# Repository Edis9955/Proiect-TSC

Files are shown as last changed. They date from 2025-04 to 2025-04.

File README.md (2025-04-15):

# Diagrama Bloc

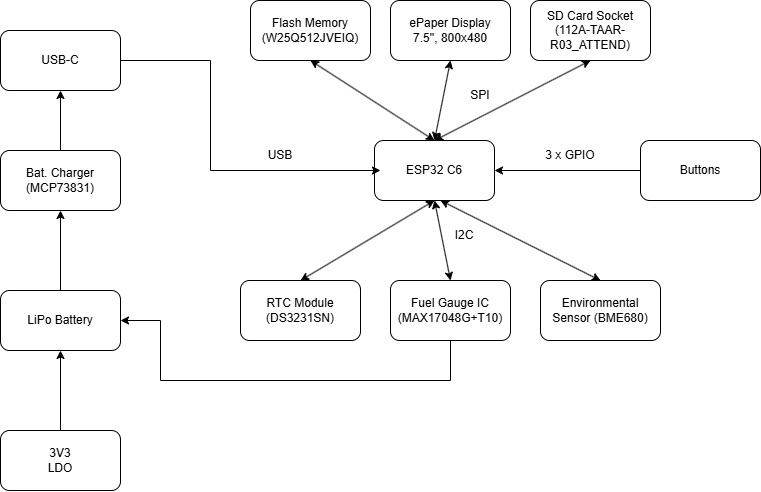
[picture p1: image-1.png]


# Bill of Materials

| Componenta | Descriere | Cumpara | Datasheet |
|---|---|---|---|
| ESP32-C6-WROOM-1-N8 | Microcontroler cu Wi-Fi 6, BLE 5.0 | [Mouser](https://ro.mouser.com/ProductDetail/Espressif-Systems/ESP32-C6-WROOM-1-N8) | [Datasheet](https://www.espressif.com/sites/default/files/documentation/esp32-c6-wroom-1_wroom-1u_datasheet_en.pdf) |
| BME680 | Senzor temperatură, umiditate, presiune, VOC | [Mouser](https://ro.mouser.com/ProductDetail/Bosch-Sensortec/BME680) | [Datasheet](https://www.bosch-sensortec.com/media/boschsensortec/downloads/datasheets/bst-bme680-ds001.pdf) |
| DS3231SN | Ceas în timp real | [Mouser](https://ro.mouser.com/ProductDetail/Analog-Devices/DS3231SN) | [Datasheet](https://www.analog.com/media/en/technical-documentation/data-sheets/DS3231.pdf) |
| W25Q512JVEIQ | Memorie Flash 64MB | [Mouser](https://ro.mouser.com/ProductDetail/Winbond/W25Q512JVEIQ) | [Datasheet](https://www.winbond.com/resource-files/W25Q512JV%20SPI%20RevB%2006252019%20KMS.pdf) |
| MicroSD Slot (112A-TAAR-R03) | Slot card microSD | [Mouser](https://ro.mouser.com/ProductDetail/Attend/112A-TAAR-R03) | [Datasheet](https://www.attend.com.tw/data/download/file/112A-TAAR-R03_Spec.pdf) |
| MCP73831T-5ACI/OT | Încărcător baterie | [Mouser](https://ro.mouser.com/ProductDetail/Microchip-Technology/MCP73831T-5ACI-OT) | [Datasheet](https://ww1.microchip.com/downloads/en/DeviceDoc/MCP73831-Family-Data-Sheet-DS20001984H.pdf) |
| MAX17048G+T10 | Indicator nivel baterie | [Mouser](https://ro.mouser.com/ProductDetail/Analog-Devices/MAX17048G%2BT10) | [Datasheet](https://www.analog.com/media/en/technical-documentation/data-sheets/MAX17048-MAX17049.pdf) |
| XC6220A331MR-G | Regulator 3.3V | [Mouser](https://ro.mouser.com/ProductDetail/Torex-Semiconductor/XC6220A331MR-G) | [Datasheet](https://www.torexsemi.com/file/xc6220/XC6220.pdf) |
| USB4110-GF-A | Conector USB-C | [Mouser](https://ro.mouser.com/ProductDetail/GCT/USB4110-GF-A) | [Datasheet](https://gct.co/files/drawings/usb4110.pdf) |
| CPH3225A | Supercondensator pentru ceas | [Mouser](https://ro.mouser.com/ProductDetail/Seiko-Instruments/CPH3225A) | [Datasheet](https://mm.digikey.com/Volume0/opasdata/d220001/medias/docus/6537/rev05-CPHCPM.pdf) |
| DMG2305UX-7 | MOSFET P-Channel | [Mouser](https://ro.mouser.com/ProductDetail/Diodes-Incorporated/DMG2305UX-7) | [Datasheet](https://www.diodes.com/assets/Datasheets/DMG2305UX.pdf) |
| SI1308EDL-T1-GE3 | MOSFET N-Channel | [Mouser](https://ro.mouser.com/ProductDetail/Vishay-Siliconix/SI1308EDL-T1-GE3) | [Datasheet](https://www.vishay.com/docs/63399/si1308edl.pdf) |
| USBLC6-2SC6Y | Protecție ESD USB | [Mouser](https://ro.mouser.com/ProductDetail/STMicroelectronics/USBLC6-2SC6Y) | [Datasheet](https://www.st.com/resource/en/datasheet/usblc6-2.pdf) |
| PGB1010603MR | Protecție ESD | [Mouser](https://ro.mouser.com/ProductDetail/Littelfuse/PGB1010603MR) | [Datasheet](https://www.littelfuse.com/~/media/electronics/datasheets/esd_protection/littelfuse_pulseguard_esd_pgb1_series_datasheet.pdf) |
| BD5229G-TR | Detector tensiune | [Mouser](https://ro.mouser.com/ProductDetail/ROHM-Semiconductor/BD5229G-TR) | [Datasheet](https://fscdn.rohm.com/en/products/databook/datasheet/ic/power/voltage_detector/bd52xxg-e.pdf) |
| FH34SRJ-24S-0.5SH(99) | Conector FFC/FPC e-paper | [Mouser](https://ro.mouser.com/ProductDetail/Hirose-Connector/FH34SRJ-24S-0.5SH99) | [Datasheet](https://www.hirose.com/product/document?clcode=&productname=&series=FH34SRJ&documenttype=Catalog&lang=en) |
| 744043680 | Inductor | [Mouser](https://ro.mouser.com/ProductDetail/Wurth-Elektronik/744043680) | [Datasheet](https://www.we-online.com/components/products/datasheet/744043680.pdf) |
| EVQPUJ02K | Buton tactil | [Mouser](https://ro.mouser.com/ProductDetail/Panasonic/EVQPUJ02K) | [Datasheet](https://www.lcsc.com/datasheet/lcsc_datasheet_2201121800_PANASONIC-EVQPUJ02K_C2936858.pdf) |
| KP-1608SURCK | LED indicator | [Mouser](https://ro.mouser.com/ProductDetail/Kingbright/KP-1608SURCK) | [Datasheet](https://media.elv.com/file/107153_led_surck1608_data.pdf) |

# Functionalitati Hardware
### ESP32-C6-WROOM-1-N8
- MCU principal, Wi-Fi 6, Bluetooth 5
- Interfețe: SPI, I2C, UART, GPIO
- 160MHz, 512KB SRAM, 8MB Flash

### Senzor BME688
- Măsoară: temperatură, umiditate, presiune, VOC
- I2C, consum redus: <1mA

### Ecran E-Paper
- Diagonală: 7.5”
- Conectare prin SPI
- Consum 0 în stare statică

### Sistem de Alimentare
- Baterie: 3.7V Li-Po 2500mAh
- Încărcare: MCP73831, max 1A
- Monitorizare: MAX17048 (Fuel Gauge)
- Consum tipic:
- Activ: ~150mA
- Standby: ~10mA
- Deep Sleep: <50µA
- Autonomie: ~250h la 10mA

### Conectivitate USB-C
- Încărcare & date (USB 2.0)
- Protecție ESD: USBLC6-2SC6Y

# Descriere pini

| Pin  | Funcție | Componentă | Descriere Utilizare |
|-----:|:---|:---|:---|
| EN  | RESET | Resetare sistem |Pin pentru resetare
| GPIO0  | BOOT_BUTTON | Buton | Boot mode la pornire |
| GPIO1  | RESET_BUTTON | Buton | Reset manual |
| GPIO2  | CHANGE_BUTTON  | Buton | Navigare meniu |
| GPIO3  | EPD_CS | Display E-Paper | Chip Select (SPI) |
| GPIO4  | EPD_DC | Display E-Paper | Data/Command control |
| GPIO5  | EPD_RST | Display E-Paper | Reset ecran |
| GPIO6  | EPD_BUSY | Display E-Paper | Semnal stare refresh |
| GPIO7  | SPI_MOSI | Display, Flash, SD  | Master Out Slave In (SPI) |
| GPIO8  | SPI_MISO | Display, Flash, SD  | Master In Slave Out (SPI) |
| GPIO9  | SPI_SCK | Display, Flash, SD  | Clock SPI |
| GPIO10 | FLASH_CS | W25Q512JVEIQ | Chip Select pentru Flash |
| GPIO11 | SD_CS | Micro SD (opțional) | Chip Select card SD |
| GPIO12 | I2C_SDA | BME680, MAX17048, DS3231 | Linie date I2C |
| GPIO13 | I2C_SCL | BME680, MAX17048, DS3231 | Linie clock I2C | 
| GPIO14 | CHG_LED | LED încărcare | Status încărcare |
| GPIO15 | UART_TX | Debugging | TX serial |
| GPIO16 | UART_RX | Debugging | RX serial |
| GPIO17 | USB_D+ | USB-C | Linie date USB + |
| GPIO18 | USB_D- | USB-C | Linie date USB – 
| GPIO21 | SDA | Linie date I²C | Comun pentru senzori si RTC |
| GPIO22 | SCL | Linie ceas I²C | Semnal comun de ceas I²C |
| GPIO23 | EPD_RST | Resetare e-paper | Resetare hardware pentru afișaj |
| TXD0 | TX | Transmitere UART (depanare) | Punct test pentru depanare |
| RXD0 | RX | Recepție UART (depanare) | Punct test pentru depanare | |

## observatii:
- fisierul Mechanical si Images nu au fost inca populate
- componentele SPI ESD Protection Lines sunt foarte grupate
- toate test pad-urile sunt pe pcb, desi in model doar 5 erau

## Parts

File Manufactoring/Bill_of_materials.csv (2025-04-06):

Qty | Value | Device | Package | Parts | Description | ARROW_PART_NUMBER | ARROW_PRICE-STOCK | AVAILABILITY | CENTROID_NOT_SPECIFIED | CHECK_PRICES | COPYRIGHT | DATASHEET | DESCRIPTION | DIGIKEY_DESCRIPTION | DIGIKEY_PART_NUMBER | FOOTPRINT | HEIGHT | LEAD_FREE | MANUFACTURER_NAME | MANUFACTURER_PART_NUMBER | MF | MFR_NAME | MOUSER_PART_NUMBER | MOUSER_PRICE-STOCK | MOUSER_TESTING_PART_NUMBER | MOUSER_TESTING_PRICE-STOCK | MP | MPN | PACKAGE | POPULARITY | PREFIX | PRICE | PROD_ID | PURCHASE-URL | ROHS | SNAPEDA_LINK | SPICEMODEL | SPICEPREFIX | TEMPERATURE_RANGE_HIGH | TEMPERATURE_RANGE_LOW | TP_SIGNAL_NAME | VALUE
1 |  | ADAFRUIT_LEDCHIP-LED0603 | ADAFRUIT_CHIP-LED0603 | CHG_LED | LED
1 |  | ESP32C6_VARISTORCN1812 | ESP32C6_VARISTOR_CT/CN1812 | PFMF.050.1 | VARISTOR |  |  |  |  |  |  |  |  |  |  |  |  |  |  |  |  |  |  |  |  |  |  |  |  | 0
1 |  | ESP32_WROVER_SPARKFUN-IC-POWER_MCP73831 | ESP32_WROVER_SPARKFUN-IC-POWER_SOT23-5 | MCP73831 | MCP73831T Li-Ion, Li-Pol Controller |  |  |  |  |  |  |  |  |  |  |  |  |  |  |  |  |  |  |  |  |  |  |  |  |  |  |  | IC-09995
1 |  | SJ | SJ | SJ1 | SMD solder JUMPER |  |  |  |  |  |  |  |  |  |  |  |  |  |  |  |  |  |  |  |  |  |  |  |  | 3
1 | 0.47 | ESP32_WROVER_EAGLE-LTSPICE_RR0402 | ESP32_WROVER_EAGLE-LTSPICE_R0402 | R3 | RESISTOR, European symbol |  |  |  |  |  |  |  |  |  |  |  |  |  |  |  |  |  |  |  |  |  |  |  |  |  |  |  |  |  |  |  | NONE | R
2 | 100K | ESP32_WROVER_EAGLE-LTSPICE_RR0402 | ESP32_WROVER_EAGLE-LTSPICE_R0402 | R1-PWRUSB, R1-PWRUSB1 | RESISTOR, European symbol |  |  |  |  |  |  |  |  |  |  |  |  |  |  |  |  |  |  |  |  |  |  |  |  |  |  |  |  |  |  |  | NONE | R
8 | 100nF | EAGLE-LTSPICE_CC0402 | EAGLE-LTSPICE_C0402 | C1, C2, C5, C6, C8, C9, C10, C_DELAY | CAPACITOR, European symbol |  |  |  |  |  |  |  |  |  |  |  |  |  |  |  |  |  |  |  |  |  |  |  |  |  |  |  |  |  |  |  | NONE | C
2 | 100nf | EAGLE-LTSPICE_CC0402 | EAGLE-LTSPICE_C0402 | C4, C4_USB | CAPACITOR, European symbol |  |  |  |  |  |  |  |  |  |  |  |  |  |  |  |  |  |  |  |  |  |  |  |  |  |  |  |  |  |  |  | NONE | C
1 | 100uF TANT | RCL_CPOL-EUCT3528 | RCL_CT3528 | C3 | POLARIZED CAPACITOR, European symbol |  |  |  |  |  |  |  |  |  |  |  |  |  |  |  |  |  |  |  |  |  |  |  |  | 0 |  |  |  |  |  |  |  | C
16 | 10K | ESP32_WROVER_EAGLE-LTSPICE_RR0402 | ESP32_WROVER_EAGLE-LTSPICE_R0402 | R1_PINH, R1_PINH1, R2_PINH, R2_PINH1, R4, R5, R6, R7, R8, R9, R10, R_BOOT, R_CAPACITOR, R_CHANGE, R_CL1, R_RESET | RESISTOR, European symbol |  |  |  |  |  |  |  |  |  |  |  |  |  |  |  |  |  |  |  |  |  |  |  |  |  |  |  |  |  |  |  | NONE | R
1 | 10uF | EAGLE-LTSPICE_CC0402 | EAGLE-LTSPICE_C0402 | C7 | CAPACITOR, European symbol |  |  |  |  |  |  |  |  |  |  |  |  |  |  |  |  |  |  |  |  |  |  |  |  |  |  |  |  |  |  |  | NONE | C
1 | 112A-TAAR-R03_ATTEND | 112A-TAAR-R03_ATTEND | 112ATAARR03ATTEND | J4 | Micro SD Card Socket, Push-Push Type, Top Mount, SMT, H=1.83mm, 10u |  |  |  |  |  |  |  | Micro SD Card Socket | Push-Push Type | Top Mount | SMT | H=1.83mm | 10u |  |  |  | 1.9mm |  | ATTEND | 112A-TAAR-R03 ATTEND
10 | 1uF/50V | EAGLE-LTSPICE_CC0402 | EAGLE-LTSPICE_C0402 | EPD_C1, EPD_C2, EPD_C5, EPD_C6, EPD_C7, EPD_C8, EPD_C9, EPD_C10, EPD_C11, EPD_C12 | CAPACITOR, European symbol |  |  |  |  |  |  |  |  |  |  |  |  |  |  |  |  |  |  |  |  |  |  |  |  |  |  |  |  |  |  |  | NONE | C
1 | 2.2 | ESP32_WROVER_EAGLE-LTSPICE_RR0402 | ESP32_WROVER_EAGLE-LTSPICE_R0402 | R2 | RESISTOR, European symbol |  |  |  |  |  |  |  |  |  |  |  |  |  |  |  |  |  |  |  |  |  |  |  |  |  |  |  |  |  |  |  | NONE | R
1 | 200 | ESP32_WROVER_EAGLE-LTSPICE_RR0402 | ESP32_WROVER_EAGLE-LTSPICE_R0402 | R1_BAT | RESISTOR, European symbol |  |  |  |  |  |  |  |  |  |  |  |  |  |  |  |  |  |  |  |  |  |  |  |  |  |  |  |  |  |  |  | NONE | R
2 | 20V/4.2A/52mO/1.4W | ESP32_WROVER_SPARKFUN-DISCRETESEMI_MOSFET_PCH-DMG2305UX-7 | ESP32_WROVER_SPARKFUN-DISCRETESEMI_SOT23-3 | Q1, Q2 | P-channel MOSFETs |  |  |  |  |  |  |  |  |  |  | DMG2305UX-7 |  |  |  |  |  |  |  |  |  |  |  |  |  |  |  |  | TRAN-14388 |  |  |  |  |  |  |  |  | 20V/4.2A/52mO/1.4W
1 | 2K | ESP32_WROVER_EAGLE-LTSPICE_RR0402 | ESP32_WROVER_EAGLE-LTSPICE_R0402 | R2_BAT | RESISTOR, European symbol |  |  |  |  |  |  |  |  |  |  |  |  |  |  |  |  |  |  |  |  |  |  |  |  |  |  |  |  |  |  |  | NONE | R
2 | 4.7uF | EAGLE-LTSPICE_CC0402 | EAGLE-LTSPICE_C0402 | C1_BAT, C2_BAT | CAPACITOR, European symbol |  |  |  |  |  |  |  |  |  |  |  |  |  |  |  |  |  |  |  |  |  |  |  |  |  |  |  |  |  |  |  | NONE | C
3 | 4.7uf | EAGLE-LTSPICE_CC0402 | EAGLE-LTSPICE_C0402 | C1_BAT1, C1_BAT2, C5_USB | CAPACITOR, European symbol |  |  |  |  |  |  |  |  |  |  |  |  |  |  |  |  |  |  |  |  |  |  |  |  |  |  |  |  |  |  |  | NONE | C
2 | 5K1 | ESP32_WROVER_EAGLE-LTSPICE_RR0402 | ESP32_WROVER_EAGLE-LTSPICE_R0402 | R2-USB1, R2-USB2 | RESISTOR, European symbol |  |  |  |  |  |  |  |  |  |  |  |  |  |  |  |  |  |  |  |  |  |  |  |  |  |  |  |  |  |  |  | NONE | R
1 | 68uH | 744043680IND_4828-WE-TPC_WRE | IND_4828-WE-TPC_WRE | L1 |  |  |  |  |  |  | Copyright (C) 2024 Ultra Librarian. All rights reserved. |  |  |  |  |  |  |  |  | 744043680 |  | Wurth Electronics
1 | BD5229G-TR | BD5229G-TR | SOT95P280X125-5N | IC11 | Voltage Detector with Adjustable Delay Time: CMOS processes are utilized to develop high precision, low current consumption CMOS reset ICs that allow arbitrary setting of the delay time. The extensive lineup includes both Nch Open Drain and CMOS output types in a wide range of detection voltages (from 2.3V to 6.0V, in 0.1V steps), enabling selection of the ideal solution based on customer requirements. In addition, the entire series is of course both lead-free and RoHS-compliant. |  |  |  |  |  |  |  | Voltage Detector with Adjustable Delay Time: CMOS processes are utilized to develop high precision | low current consumption CMOS reset ICs that allow arbitrary setting of the delay time. The extensive lineup includes both Nch Open Drain and CMOS output types in a wide range of detection voltages (from 2.3V to 6.0V | in 0.1V steps) | enabling selection of the ideal solution based on customer requirements. In addition | the entire series is of course both lead-free and RoHS-compliant. |  |  |  | 1.25mm |  | ROHM Semiconductor | BD5229G-TR |  |  | 755-BD5229G-TR | https://www.mouser.co.uk/ProductDetail/ROHM-Semiconductor/BD5229G-TR?qs=4kLU8WoGk0vvnhrrYwdszw%3D%3D
1 | BME688 | ESP32_WROVER_BME680_BME680 | ESP32_WROVER_BME680_PSON80P300X300X100-8N | SENSOR2 | Integrated Environmental Unit |  |  | Unavailable |  |  |  |  | Integrated Environmental Unit |  |  |  |  |  |  |  | Bosch Sensortec |  |  |  |  |  | BME680 |  | LGA-8 Bosch Tools |  |  | None
3 | BUTTON_CUSYOMV1 | BUTTON_CUSYOMV1 | MYBUTTON | BOOT_BUTTON, CHANGE_BUTTON, RESET_BUTTON
1 | CPH3225A | CPH3225A | CAPCP3225X100N | C10_SUPERCAP | Cap 0.011F 3.3V 1210 Flat Check availability |  |  | Not in stock |  | https://www.snapeda.com/parts/CPH3225A/Seiko+Instruments/view-part/?ref=eda |  |  | 11 mF (EDLC) Supercapacitor 3.3 V 1210 (3225 Metric) - - |  |  |  |  |  |  |  | Seiko Instruments |  |  |  |  |  | CPH3225A |  | 1210 Seiko |  |  | None |  | https://www.snapeda.com/api/url_track_click_mouser/?unipart_id=562593&manufacturer=Seiko Instruments&part_name=CPH3225A&search_term=None |  | https://www.snapeda.com/parts/CPH3225A/Seiko+Instruments/view-part/?ref=snap
1 | DS3231SN# | DS3231SN# | SOIC127P1032X265-16N | U11 | Real Time Clock Serial 16-Pin SOIC W T/R Check availability |  |  | In Stock |  | https://www.snapeda.com/parts/DS3231SN%23/Analog+Devices/view-part/?ref=eda |  |  | Extremely Accurate I²C-Integrated RTC/TCXO/Crystal |  |  |  |  |  |  |  | Analog Devices |  |  |  |  |  | DS3231SN# |  | SOIC-16 Maxim |  |  | None |  | https://www.snapeda.com/api/url_track_click_mouser/?unipart_id=99048&manufacturer=Analog Devices&part_name=DS3231SN#&search_term=None |  | https://www.snapeda.com/parts/DS3231SN%23/Analog+Devices/view-part/?ref=snap
1 | ESP32-C6-WROOM-1-N8 | ESP32-C6-WROOM-1-N8 | XCVR_ESP32-C6-WROOM-1-N8 | U21 | Check availability |  |  | In Stock |  | https://www.snapeda.com/parts/ESP32-C6-WROOM-1-N8/Espressif+Systems/view-part/?ref=eda |  |  | Multiprotocol Modules ESP32-C6 module | Wi-Fi 6 in 2.4 GHz band | Bluetooth 5 | Zigbee 3.0 and Thread. ESP34-WROOM Compatible - ENGINEERING SAMPLE |  |  |  |  |  |  |  | Espressif Systems |  |  |  |  |  | ESP32-C6-WROOM-1-N8 |  | None |  |  | None |  |  |  | https://www.snapeda.com/parts/ESP32-C6-WROOM-1-N8/Espressif+Systems/view-part/?ref=snap
2 | ESP32_WROVER_AVX---SD0805S020S1R0_AVX_SD0805S020S1R0_0_0AVX_SD0805S020S1R0_0_0 | ESP32_WROVER_AVX---SD0805S020S1R0_AVX_SD0805S020S1R0_0_0AVX_SD0805S020S1R0_0_0 | ESP32_WROVER_AVX---SD0805S020S1R0_AVX_SD0805S020S1R0_0 | D2, D7 | Schottky Barrier Rectifier Diode |  |  |  | No |  |  | http://datasheets.avx.com/schottky.pdf |  | DIODE SCHOTTKY 20V 1A 0805 | 478-7800-1-ND | SD0805S020S1R0 |  | yes |  |  | AVX |  | 581-SD0805S020S1R0 |  |  |  |  |  | 0805 (2012 metric) |  | D |  |  |  | yes |  |  |  | +125°C | -55°C
1 | FH34SRJ-24S-0.5SH_99_ | FH34SRJ-24S-0.5SH_99_ | FH34SRJ24S05SH99 | J1 | (0.50mm) Surface Mount, Right Angle |  |  |  |  |  |  |  | 24 Position FFC | FPC Connector Contacts | (0.50mm) Surface Mount | Right Angle |  |  |  | 1.1mm |  | Hirose | FH34SRJ-24S-0.5SH(99) |  |  | 798-FH34SRJ24S05SH99 | https://www.mouser.co.uk/ProductDetail/Hirose-Connector/FH34SRJ-24S-0.5SH99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
1 | MAX17048G+T10 | MAX17048G+T10 | SON50P200X200X80-9N | U4 | Check availability |  |  | In Stock |  | https://www.snapeda.com/parts/MAX17048G+T10/Analog+Devices/view-part/?ref=eda |  |  | 3µA 1-Cell/2-Cell Fuel Gauge with ModelGauge |  |  |  |  |  |  |  | Analog Devices |  |  |  |  |  | MAX17048G+T10 |  | TDFN-8 Maxim |  |  | None |  | https://www.snapeda.com/api/url_track_click_mouser/?unipart_id=329239&manufacturer=Analog Devices&part_name=MAX17048G+T10&search_term=None |  | https://www.snapeda.com/parts/MAX17048G+T10/Analog+Devices/view-part/?ref=snap
3 | MBR0530 | MBR0530 | SOD3716X135N | D3, D4, D5 | ON SEMICONDUCTOR - MBR0530 - DIODE, SCHOTTKY, 0.5A, 30V, SOD-123 |  |  | In Stock |  | https://www.snapeda.com/parts/MBR0530/Onsemi/view-part/?ref=eda |  |  | Diode Schottky 30 V 500mA Surface Mount SOD-123 |  |  |  |  |  |  |  | ON Semiconductor |  |  |  |  |  | MBR0530 |  | SOD-123-2 ON Semiconductor |  |  | None |  | https://www.snapeda.com/api/url_track_click_mouser/?unipart_id=179458&manufacturer=ON Semiconductor&part_name=MBR0530&search_term=None |  | https://www.snapeda.com/parts/MBR0530/Onsemi/view-part/?ref=snap
6 | PGB1010603MR | PGB1010603MR | DIOC1608X36N | D6, D8, D9, D10, D12, D13 | Check availability |  |  | In Stock |  | https://www.snapeda.com/parts/PGB1010603MR/Littelfuse/view-part/?ref=eda |  |  | 150V (Typ) Clamp - Ipp Tvs Diode Surface Mount 0603 (1608 Metric) |  |  |  |  |  |  |  | Littelfuse Inc. |  |  |  |  |  | PGB1010603MR |  | 0603 Littelfuse Inc. |  |  | None |  | https://www.snapeda.com/api/url_track_click_mouser/?unipart_id=5659453&manufacturer=Littelfuse Inc.&part_name=PGB1010603MR&search_term=None |  | https://www.snapeda.com/parts/PGB1010603MR/Littelfuse/view-part/?ref=snap
1 | QWIIC_RIGHT_ANGLE | QWIIC_CONNECTORJS-1MM | JST04_1MM_RA | J3 | SparkFun I2C Standard Qwiic Connector |  |  |  |  |  |  |  |  |  |  |  |  |  |  |  |  |  |  |  |  |  |  |  |  |  |  |  | CONN-13694 |  |  |  |  |  |  |  |  | QWIIC_RIGHT_ANGLE
1 | SAMACSYS_PARTS_USB4110-GF-A | SAMACSYS_PARTS_USB4110-GF-A | SAMACSYS_PARTS_USB4110GFA | J2 | CONN USB 2.0 TYPE-C R/A SMT |  |  |  |  |  |  |  | CONN USB 2.0 TYPE-C R/A SMT |  |  |  | 3.26mm |  | GCT (GLOBAL CONNECTOR TECHNOLOGY) | USB4110-GF-A |  |  | 640-USB4110-GF-A | https://www.mouser.co.uk/ProductDetail/GCT/USB4110-GF-A?qs=KUoIvG%2F9IlYiZvIXQjyJeA%3D%3D
1 | SI1308EDL-T1-GE3 | SI1308EDL-T1-GE3 | SOT65P210X110-3N | Q3 | MOSFET N-Ch 30V 1.5A TrenchFET SC70 Vishay Si1308EDL-T1-GE3 N-channel MOSFET Transistor, 1.5 A, 30 V, 3-Pin SC-70 |  |  | In Stock |  | https://www.snapeda.com/parts/SI1308EDL-T1-GE3/Vishay+Siliconix/view-part/?ref=eda |  |  | Si1308EDL-T1-GE3 N-channel MOSFET Transistor | 1.5 A | 30 V | 3-Pin SC-70 | Siliconix / Vishay SI1308EDL-T1-GE3 |  |  |  |  |  |  |  | Vishay Siliconix |  |  |  |  |  | SI1308EDL-T1-GE3 |  | SOT-323 Vishay Semiconductor |  |  | None |  | https://www.snapeda.com/api/url_track_click_mouser/?unipart_id=274603&manufacturer=Vishay Siliconix&part_name=SI1308EDL-T1-GE3&search_term=None |  | https://www.snapeda.com/parts/SI1308EDL-T1-GE3/Vishay+Siliconix/view-part/?ref=snap
17 | TPTP20R | TPTP20R | TP20R | TP1, TP2, TP3, TP4, TP5, TP6, TP7, TP8, TP9, TP10, TP11, TP12, TP13, TP14, TP15, TP16, TP17 | Test pad |  |  |  |  |  |  |  |  |  |  |  |  |  |  |  |  |  |  |  |  |  |  |  |  | 2
1 | USBLC6-2SC6Y | USBLC6-2SC6Y | SOT95P280X145-6N | D1 | Low Cap. ESD Protection Auto SOT-23-6 STMicroelectronics USBLC6-2SC6Y, Dual Uni-Directional TVS Diode Array, 6-Pin SOT-23 |  |  | In Stock |  | https://www.snapeda.com/parts/USBLC6-2SC6Y/STMicroelectronics/view-part/?ref=eda |  |  | 17V Clamp 5A (8/20µs) Ipp Tvs Diode Surface Mount SOT-23-6 |  |  |  |  |  |  |  | STMicroelectronics |  |  |  |  |  | USBLC6-2SC6Y |  | SOT-23-6 STMicroelectronics |  |  | None |  |  |  | https://www.snapeda.com/parts/USBLC6-2SC6Y/STMicroelectronics/view-part/?ref=snap
1 | W25Q512JVEIQ | W25Q512JVEIQ | SON127P600X800X80-9N | U1 | Check availability |  |  | In Stock |  | https://www.snapeda.com/parts/W25Q512JVEIQ/Winbond+Electronics/view-part/?ref=eda |  |  | FLASH - NOR Memory IC 512Mb (64M x 8) SPI - Quad I/O 133 MHz 8-WSON (8x6) |  |  |  |  |  |  |  | Winbond Electronics |  |  |  |  |  | W25Q512JVEIQ |  | Package |  |  | None |  |  |  | https://www.snapeda.com/parts/W25Q512JVEIQ/Winbond+Electronics/view-part/?ref=snap
1 | XC6220A331MR-G | XC6220A331MR-G | SOT95P280X120-5N | IC4 | LDO Voltage Regulators |  |  |  |  |  |  |  | LDO Voltage Regulators |  |  |  | 1.2mm |  | Torex | XC6220A331MR-G |  |  | 865-XC6220A331MR-G | https://www.mouser.co.uk/ProductDetail/Torex-Semiconductor/XC6220A331MR-G?qs=AsjdqWjXhJ8ZSWznL1J0gg%3D%3D

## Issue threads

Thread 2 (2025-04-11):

[invalid] CAD ERC errors

Alexandru730, 2025-04-11:
Ai aprobat 16 erori in schematic, verificarea ERC nu este completa si curata si nu vei putea sa faci randarea in 3D. Singura eroare pe care poti sa o ignori este “Only INPUT pins on NET ID”.

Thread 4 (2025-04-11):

[bug] Wrong placed component

Alexandru730, 2025-04-11:
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

Aici trebuia sa o pozitionezi ca in schema data pentru ca o sa ai nevoie de ea pusa la fix pentru potrivirea placutei in carcasa, acea componenta este mufa usb-c si daca o vei lasa asa o sa fii nevoit sa modifici tu carcasa ca sa se potriveasca.

Closed 2025-04-15.
